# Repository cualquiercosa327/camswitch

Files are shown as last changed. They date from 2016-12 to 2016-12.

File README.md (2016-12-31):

# Little Camera Switcher

A special purpose keyboard with 15 keys, intended for hotkeying camera switches in Open Broadcast Studio. It's just a keyboard built with the Teensy 2.0, but it's made to be flexible and magnetic so it can attach to flat or curved metal surfaces.

This repository includes the Arduino sketches, CAD models in Rhino and STL format, and PCB layout in KiCad and Gerber. I fabricated the flex circuit on Pyralux using milling, but you can also use photochemical etching or toner transfer.

Everything here is dedicated to the public domain. ([CC0](https://wiki.creativecommons.org/wiki/CC0))

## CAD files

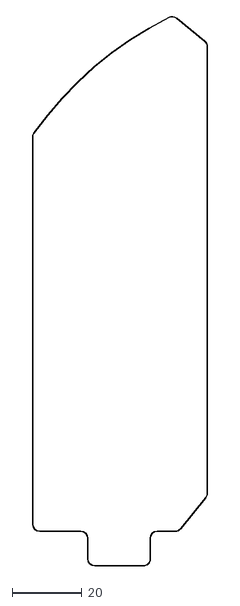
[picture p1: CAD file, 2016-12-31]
enclosure/pcb-outline.dxf
50.0 x 157.3

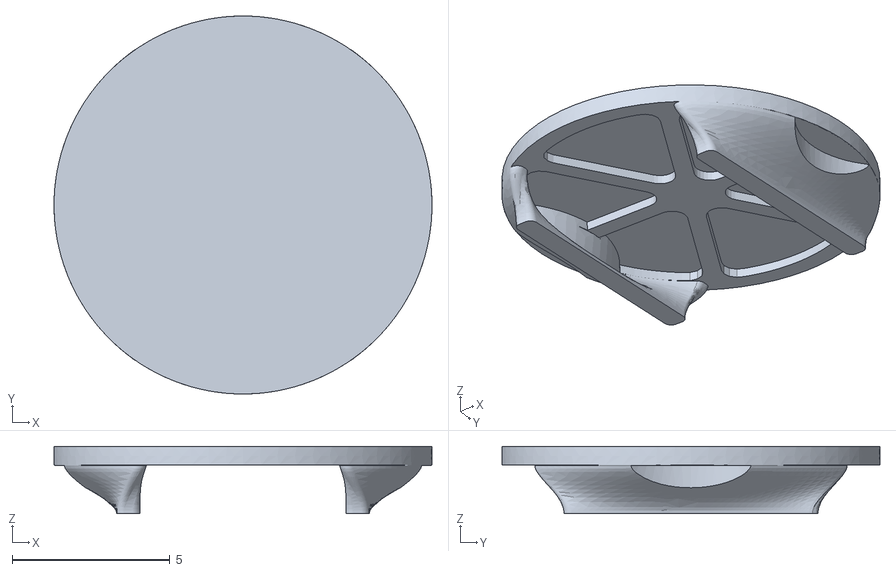
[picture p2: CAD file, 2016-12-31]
enclosure/prints/camswitch-key-insert-2.stl
12.0 x 12.0 x 2.14

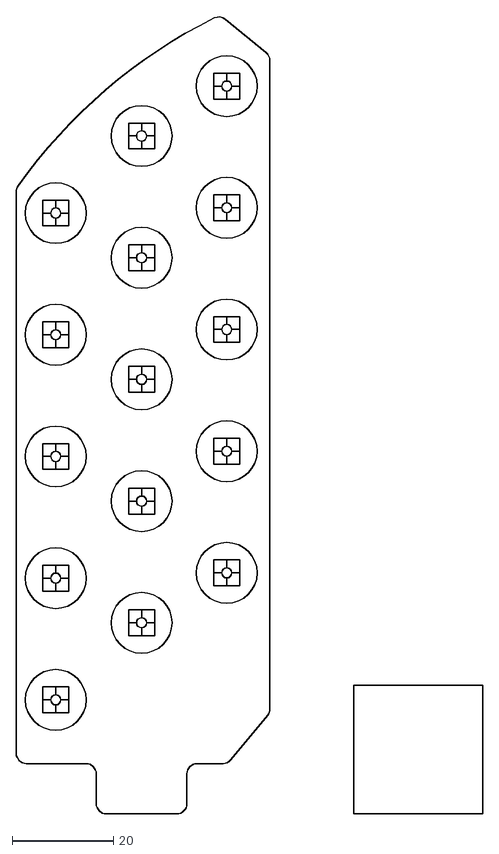
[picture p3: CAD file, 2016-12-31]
flexpcb/pcb-mechanical-constraints.dxf
92.0 x 157.3

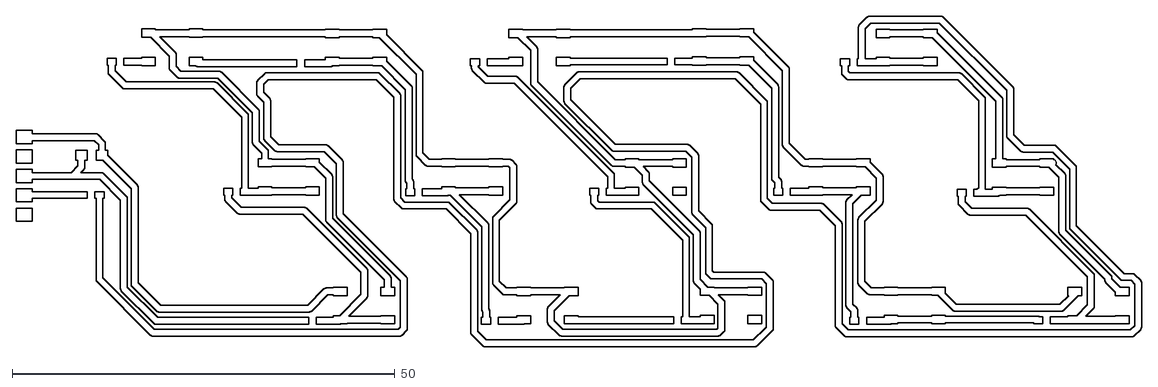
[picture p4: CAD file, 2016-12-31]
flexpcb/plots/camswitch-flexpcb-F.Cu.dxf
147.1 x 43.2

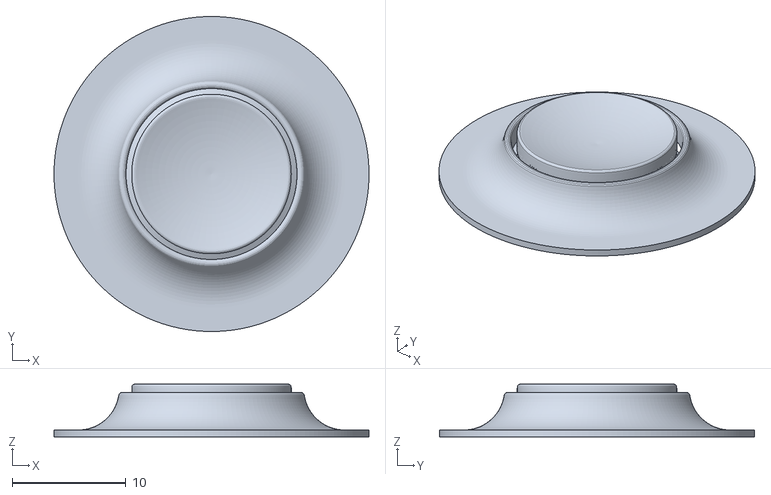
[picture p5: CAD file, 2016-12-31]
enclosure/prints/button-cover-test-8.stl
27.6 x 27.6 x 4.62

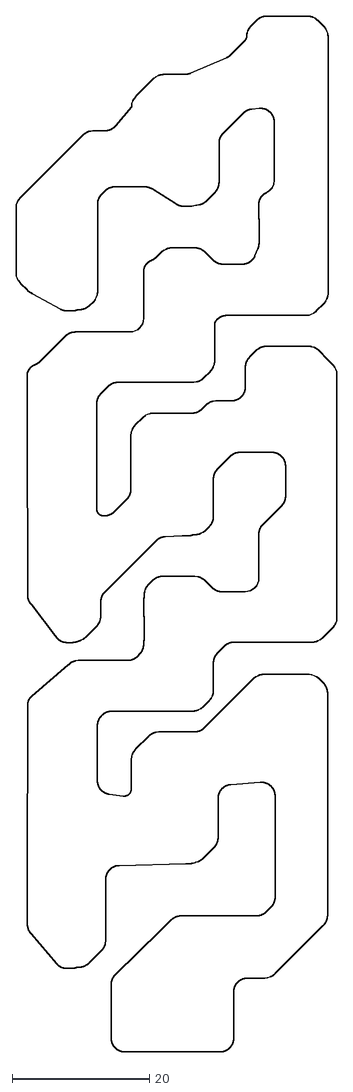
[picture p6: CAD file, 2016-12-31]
flexpcb/camswitch-curvy-outline.dxf
46.8 x 151.0

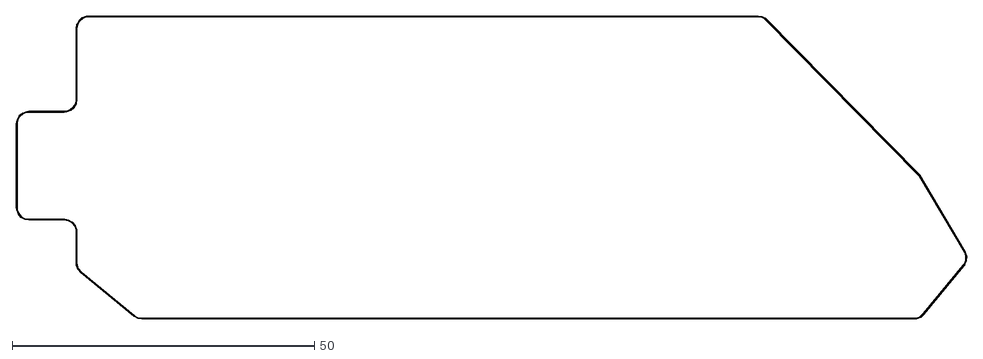
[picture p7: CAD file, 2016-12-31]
flexpcb/plots/camswitch-flexpcb-Edge.Cuts.dxf
157.2 x 50.1

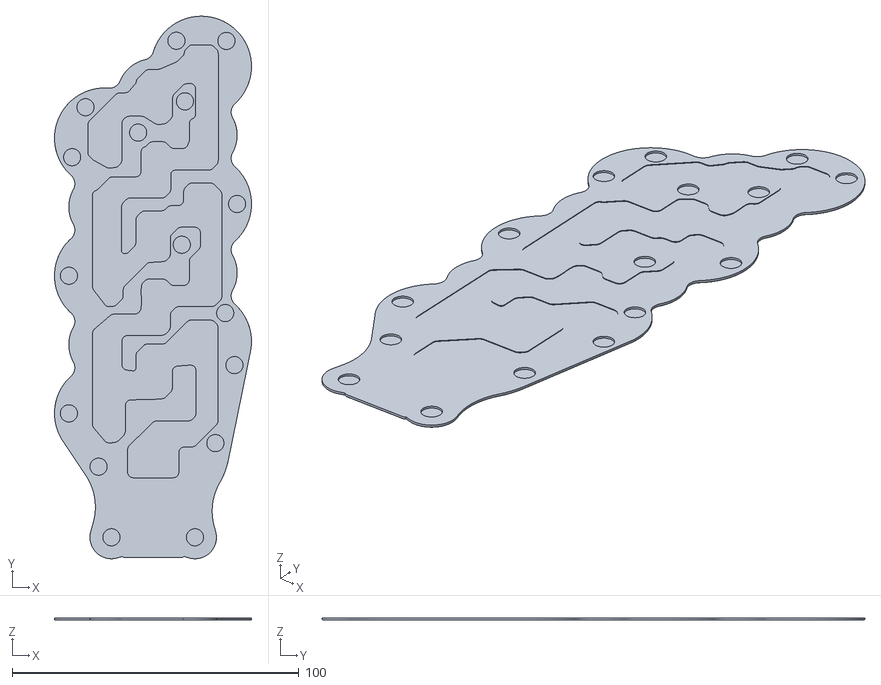
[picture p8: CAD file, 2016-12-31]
enclosure/prints/camswitch-bottom-1.stl
68.7 x 189.3 x 0.8

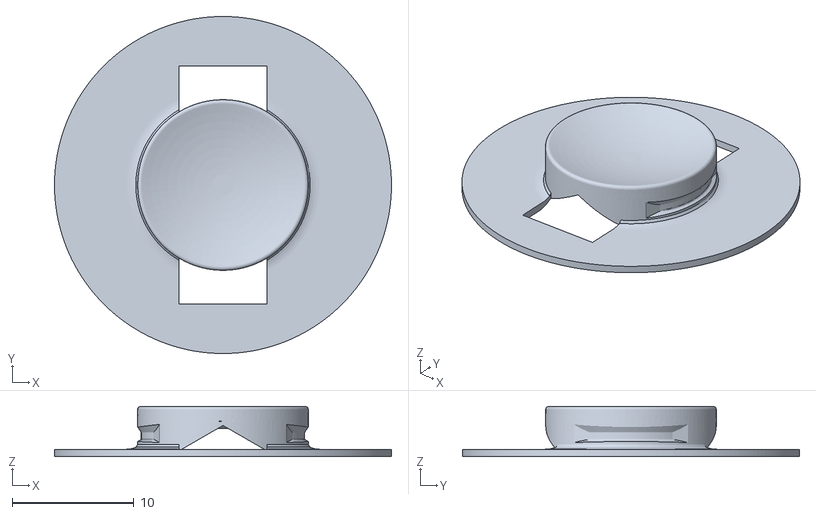
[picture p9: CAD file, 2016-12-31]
enclosure/prints/button-cover-test-6.stl
27.6 x 27.6 x 4.12

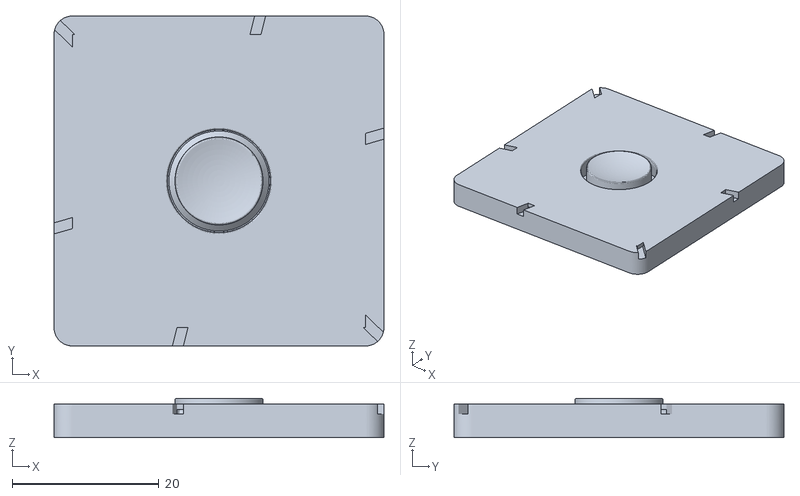
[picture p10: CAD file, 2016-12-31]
enclosure/prints/button-cover-test-1.stl
45.0 x 45.0 x 5.38

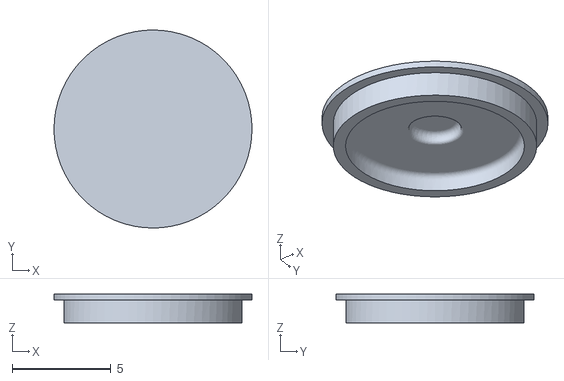
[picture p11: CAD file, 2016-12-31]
enclosure/prints/camswitch-key-insert.stl
10.00 x 10.0 x 1.45

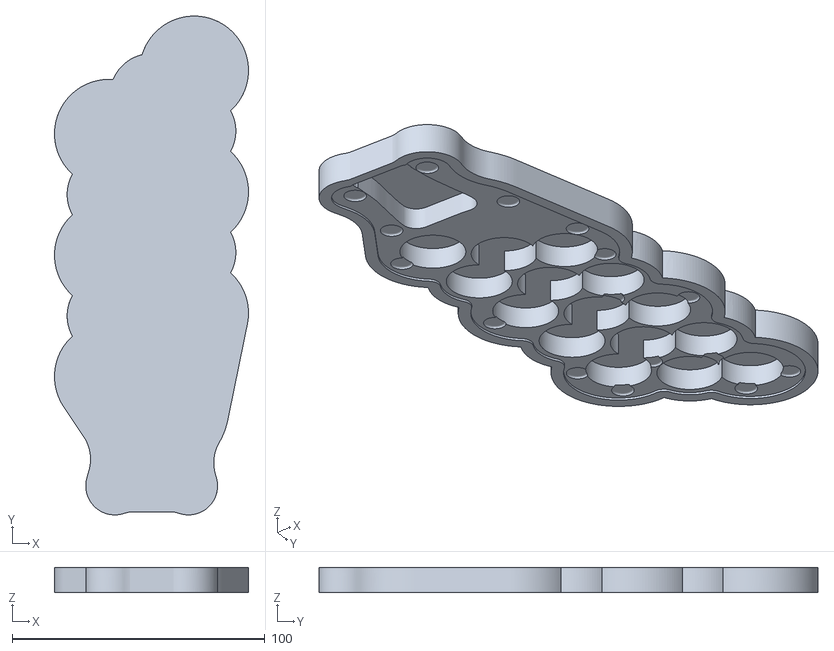
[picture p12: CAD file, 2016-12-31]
enclosure/prints/glueup-jig-1.stl
76.7 x 197.3 x 10.00

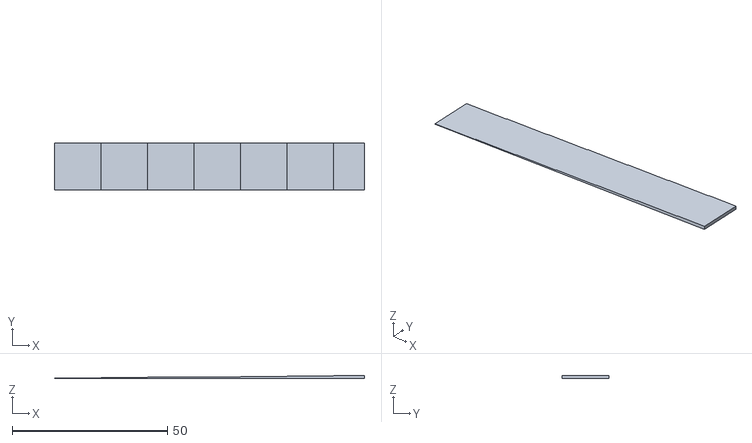
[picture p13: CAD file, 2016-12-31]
enclosure/prints/ninjaflex-thickness-test.stl
100.0 x 15.0 x 1.05

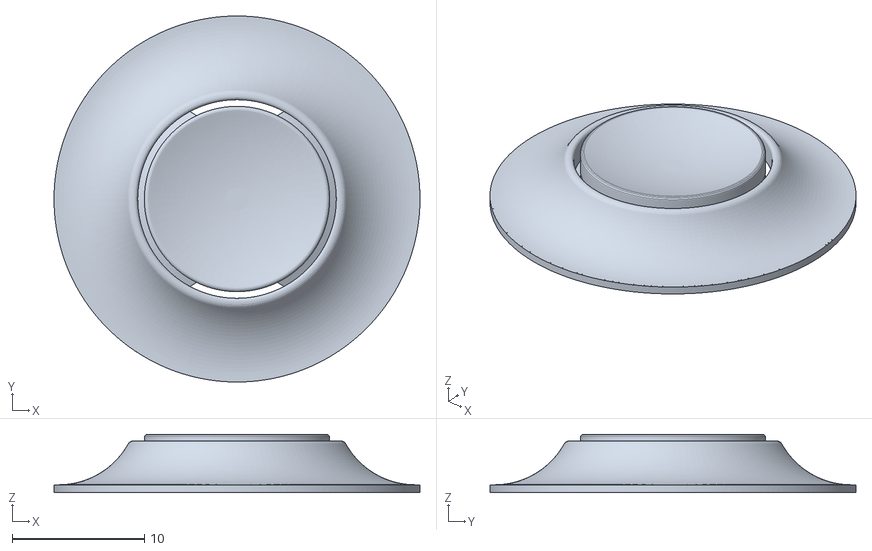
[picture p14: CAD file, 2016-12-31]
enclosure/prints/button-cover-test-7.stl
27.7 x 27.6 x 4.41

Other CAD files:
enclosure/button-module.3dm
enclosure/button-profile.3dm
enclosure/camswitcher.3dm

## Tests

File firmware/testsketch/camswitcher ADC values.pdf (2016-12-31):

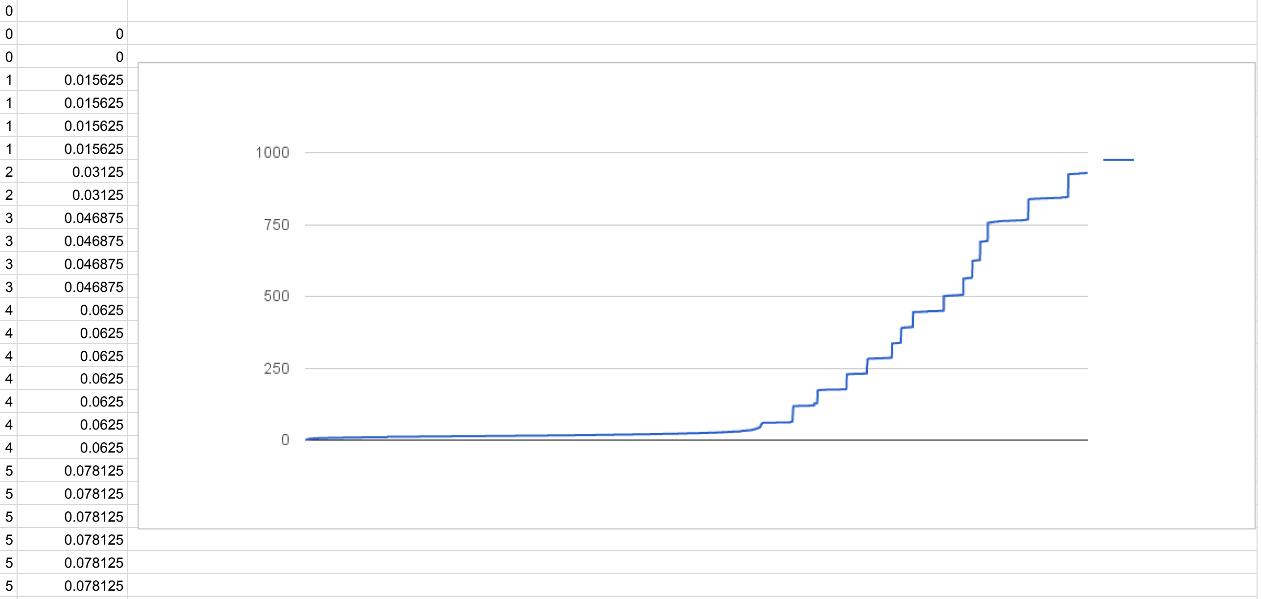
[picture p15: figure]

5 | 0.078125
5 | 0.078125
5 | 0.078125
5 | 0.078125
5 | 0.078125
6 | 0.09375
6 | 0.09375
6 | 0.09375
6 | 0.09375
6 | 0.09375
6 | 0.09375
6 | 0.09375
6 | 0.09375
6 | 0.09375
6 | 0.09375
6 | 0.09375
6 | 0.09375

6 | 0.09375
6 | 0.09375
6 | 0.09375
6 | 0.09375
6 | 0.09375
6 | 0.09375
6 | 0.09375
6 | 0.09375
6 | 0.09375
6 | 0.09375
7 | 0.109375
7 | 0.109375
7 | 0.109375
7 | 0.109375
7 | 0.109375
7 | 0.109375
7 | 0.109375
7 | 0.109375
7 | 0.109375
7 | 0.109375
7 | 0.109375
7 | 0.109375
7 | 0.109375
7 | 0.109375
7 | 0.109375
7 | 0.109375
7 | 0.109375
7 | 0.109375
7 | 0.109375
7 | 0.109375
7 | 0.109375
7 | 0.109375
7 | 0.109375
7 | 0.109375
7 | 0.109375
7 | 0.109375
7 | 0.109375
7 | 0.109375
7 | 0.109375
7 | 0.109375
7 | 0.109375
7 | 0.109375
7 | 0.109375

7 | 0.109375
7 | 0.109375
7 | 0.109375
7 | 0.109375
7 | 0.109375
7 | 0.109375
8 | 0.125
8 | 0.125
8 | 0.125
8 | 0.125
8 | 0.125
8 | 0.125
8 | 0.125
8 | 0.125
8 | 0.125
8 | 0.125
8 | 0.125
8 | 0.125
8 | 0.125
8 | 0.125
8 | 0.125
8 | 0.125
8 | 0.125
8 | 0.125
8 | 0.125
8 | 0.125
8 | 0.125
8 | 0.125
8 | 0.125
8 | 0.125
8 | 0.125
8 | 0.125
8 | 0.125
8 | 0.125
8 | 0.125
8 | 0.125
8 | 0.125
8 | 0.125
8 | 0.125
8 | 0.125
8 | 0.125
8 | 0.125

8 | 0.125
8 | 0.125
8 | 0.125
8 | 0.125
8 | 0.125
8 | 0.125
8 | 0.125
8 | 0.125
8 | 0.125
8 | 0.125
8 | 0.125
8 | 0.125
8 | 0.125
8 | 0.125
8 | 0.125
8 | 0.125
8 | 0.125
8 | 0.125
8 | 0.125
8 | 0.125
8 | 0.125
8 | 0.125
8 | 0.125
8 | 0.125
8 | 0.125
8 | 0.125
9 | 0.140625
9 | 0.140625
9 | 0.140625
9 | 0.140625
9 | 0.140625
9 | 0.140625
9 | 0.140625
9 | 0.140625
9 | 0.140625
9 | 0.140625
9 | 0.140625
9 | 0.140625
9 | 0.140625
9 | 0.140625
9 | 0.140625
9 | 0.140625

9 | 0.140625
9 | 0.140625
9 | 0.140625
9 | 0.140625
9 | 0.140625
9 | 0.140625
9 | 0.140625
9 | 0.140625
9 | 0.140625
9 | 0.140625
9 | 0.140625
9 | 0.140625
9 | 0.140625
9 | 0.140625
9 | 0.140625
9 | 0.140625
9 | 0.140625
9 | 0.140625
9 | 0.140625
9 | 0.140625
9 | 0.140625
9 | 0.140625
9 | 0.140625
9 | 0.140625
9 | 0.140625
9 | 0.140625
9 | 0.140625
9 | 0.140625
9 | 0.140625
9 | 0.140625
9 | 0.140625
9 | 0.140625
9 | 0.140625
9 | 0.140625
9 | 0.140625
9 | 0.140625
9 | 0.140625
9 | 0.140625
9 | 0.140625
9 | 0.140625
9 | 0.140625
9 | 0.140625

9 | 0.140625
9 | 0.140625
9 | 0.140625
9 | 0.140625
9 | 0.140625
9 | 0.140625
9 | 0.140625
9 | 0.140625
9 | 0.140625
9 | 0.140625
9 | 0.140625
9 | 0.140625
9 | 0.140625
9 | 0.140625
9 | 0.140625
9 | 0.140625
9 | 0.140625
9 | 0.140625
10 | 0.15625
10 | 0.15625
10 | 0.15625
10 | 0.15625
10 | 0.15625
10 | 0.15625
10 | 0.15625
10 | 0.15625
10 | 0.15625
10 | 0.15625
10 | 0.15625
10 | 0.15625
10 | 0.15625
10 | 0.15625
10 | 0.15625
10 | 0.15625
10 | 0.15625
10 | 0.15625
10 | 0.15625
10 | 0.15625
10 | 0.15625
10 | 0.15625
10 | 0.15625
10 | 0.15625

10 | 0.15625
10 | 0.15625
10 | 0.15625
10 | 0.15625
10 | 0.15625
10 | 0.15625
10 | 0.15625
10 | 0.15625
10 | 0.15625
10 | 0.15625
10 | 0.15625
10 | 0.15625
10 | 0.15625
10 | 0.15625
10 | 0.15625
10 | 0.15625
10 | 0.15625
10 | 0.15625
10 | 0.15625
10 | 0.15625
10 | 0.15625
10 | 0.15625
10 | 0.15625
10 | 0.15625
10 | 0.15625
10 | 0.15625
10 | 0.15625
10 | 0.15625
10 | 0.15625
10 | 0.15625
10 | 0.15625
10 | 0.15625
10 | 0.15625
10 | 0.15625
10 | 0.15625
10 | 0.15625
10 | 0.15625
10 | 0.15625
10 | 0.15625
10 | 0.15625
10 | 0.15625
10 | 0.15625

10 | 0.15625
10 | 0.15625
10 | 0.15625
10 | 0.15625
10 | 0.15625
10 | 0.15625
10 | 0.15625
10 | 0.15625
10 | 0.15625
10 | 0.15625
10 | 0.15625
10 | 0.15625
10 | 0.15625
10 | 0.15625
10 | 0.15625
10 | 0.15625
10 | 0.15625
10 | 0.15625
10 | 0.15625
10 | 0.15625
10 | 0.15625
10 | 0.15625
10 | 0.15625
10 | 0.15625
10 | 0.15625
10 | 0.15625
10 | 0.15625
10 | 0.15625
10 | 0.15625
10 | 0.15625
10 | 0.15625
10 | 0.15625
10 | 0.15625
10 | 0.15625
10 | 0.15625
10 | 0.15625
10 | 0.15625
10 | 0.15625
11 | 0.171875
11 | 0.171875
11 | 0.171875
11 | 0.171875

11 | 0.171875
11 | 0.171875
11 | 0.171875
11 | 0.171875
11 | 0.171875
11 | 0.171875
11 | 0.171875
11 | 0.171875
11 | 0.171875
11 | 0.171875
11 | 0.171875
11 | 0.171875
11 | 0.171875
11 | 0.171875
11 | 0.171875
11 | 0.171875
11 | 0.171875
11 | 0.171875
11 | 0.171875
11 | 0.171875
11 | 0.171875
11 | 0.171875
11 | 0.171875
11 | 0.171875
11 | 0.171875
11 | 0.171875
11 | 0.171875
11 | 0.171875
11 | 0.171875
11 | 0.171875
11 | 0.171875
11 | 0.171875
11 | 0.171875
11 | 0.171875
11 | 0.171875
11 | 0.171875
11 | 0.171875
11 | 0.171875
11 | 0.171875
11 | 0.171875
11 | 0.171875
11 | 0.171875

11 | 0.171875
11 | 0.171875
11 | 0.171875
11 | 0.171875
11 | 0.171875
11 | 0.171875
11 | 0.171875
11 | 0.171875
11 | 0.171875
11 | 0.171875
11 | 0.171875
11 | 0.171875
11 | 0.171875
11 | 0.171875
11 | 0.171875
11 | 0.171875
11 | 0.171875
11 | 0.171875
11 | 0.171875
11 | 0.171875
11 | 0.171875
11 | 0.171875
11 | 0.171875
11 | 0.171875
11 | 0.171875
11 | 0.171875
11 | 0.171875
11 | 0.171875
11 | 0.171875
11 | 0.171875
11 | 0.171875
11 | 0.171875
11 | 0.171875
11 | 0.171875
11 | 0.171875
11 | 0.171875
11 | 0.171875
11 | 0.171875
11 | 0.171875
11 | 0.171875
11 | 0.171875
11 | 0.171875

11 | 0.171875
11 | 0.171875
11 | 0.171875
11 | 0.171875
11 | 0.171875
11 | 0.171875
11 | 0.171875
11 | 0.171875
11 | 0.171875
11 | 0.171875
11 | 0.171875
11 | 0.171875
11 | 0.171875
11 | 0.171875
11 | 0.171875
11 | 0.171875
11 | 0.171875
11 | 0.171875
11 | 0.171875
11 | 0.171875
11 | 0.171875
11 | 0.171875
11 | 0.171875
11 | 0.171875
11 | 0.171875
11 | 0.171875
11 | 0.171875
11 | 0.171875
11 | 0.171875
11 | 0.171875
11 | 0.171875
11 | 0.171875
11 | 0.171875
11 | 0.171875
11 | 0.171875
11 | 0.171875
11 | 0.171875
11 | 0.171875
11 | 0.171875
11 | 0.171875
11 | 0.171875
12 | 0.1875

12 | 0.1875
12 | 0.1875
12 | 0.1875
12 | 0.1875
12 | 0.1875
12 | 0.1875
12 | 0.1875
12 | 0.1875
12 | 0.1875
12 | 0.1875
12 | 0.1875
12 | 0.1875
12 | 0.1875
12 | 0.1875
12 | 0.1875
12 | 0.1875
12 | 0.1875
12 | 0.1875
12 | 0.1875
12 | 0.1875
12 | 0.1875
12 | 0.1875
12 | 0.1875
12 | 0.1875
12 | 0.1875
12 | 0.1875
12 | 0.1875
12 | 0.1875
12 | 0.1875
12 | 0.1875
12 | 0.1875
12 | 0.1875
12 | 0.1875
12 | 0.1875
12 | 0.1875
12 | 0.1875
12 | 0.1875
12 | 0.1875
12 | 0.1875
12 | 0.1875
12 | 0.1875
12 | 0.1875

12 | 0.1875
12 | 0.1875
12 | 0.1875
12 | 0.1875
12 | 0.1875
12 | 0.1875
12 | 0.1875
12 | 0.1875
12 | 0.1875
12 | 0.1875
12 | 0.1875
12 | 0.1875
12 | 0.1875
12 | 0.1875
12 | 0.1875
12 | 0.1875
12 | 0.1875
12 | 0.1875
12 | 0.1875
12 | 0.1875
12 | 0.1875
12 | 0.1875
12 | 0.1875
12 | 0.1875
12 | 0.1875
12 | 0.1875
12 | 0.1875
12 | 0.1875
12 | 0.1875
12 | 0.1875
12 | 0.1875
12 | 0.1875
12 | 0.1875
12 | 0.1875
12 | 0.1875
12 | 0.1875
12 | 0.1875
12 | 0.1875
12 | 0.1875
12 | 0.1875
12 | 0.1875
12 | 0.1875

12 | 0.1875
12 | 0.1875
12 | 0.1875
12 | 0.1875
12 | 0.1875
12 | 0.1875
12 | 0.1875
12 | 0.1875
12 | 0.1875
12 | 0.1875
12 | 0.1875
12 | 0.1875
12 | 0.1875
12 | 0.1875
12 | 0.1875
12 | 0.1875
12 | 0.1875
12 | 0.1875
12 | 0.1875
12 | 0.1875
12 | 0.1875
12 | 0.1875
12 | 0.1875
12 | 0.1875
12 | 0.1875
12 | 0.1875
12 | 0.1875
12 | 0.1875
12 | 0.1875
12 | 0.1875
12 | 0.1875
12 | 0.1875
12 | 0.1875
12 | 0.1875
12 | 0.1875
12 | 0.1875
12 | 0.1875
12 | 0.1875
12 | 0.1875
12 | 0.1875
12 | 0.1875
12 | 0.1875

12 | 0.1875
12 | 0.1875
12 | 0.1875
12 | 0.1875
13 | 0.203125
13 | 0.203125
13 | 0.203125
13 | 0.203125
13 | 0.203125
13 | 0.203125
13 | 0.203125
13 | 0.203125
13 | 0.203125
13 | 0.203125
13 | 0.203125
13 | 0.203125
13 | 0.203125
13 | 0.203125
13 | 0.203125
13 | 0.203125
13 | 0.203125
13 | 0.203125
13 | 0.203125
13 | 0.203125
13 | 0.203125
13 | 0.203125
13 | 0.203125
13 | 0.203125
13 | 0.203125
13 | 0.203125
13 | 0.203125
13 | 0.203125
13 | 0.203125
13 | 0.203125
13 | 0.203125
13 | 0.203125
13 | 0.203125
13 | 0.203125
13 | 0.203125
13 | 0.203125
13 | 0.203125
13 | 0.203125

13 | 0.203125
13 | 0.203125
13 | 0.203125
13 | 0.203125
13 | 0.203125
13 | 0.203125
13 | 0.203125
13 | 0.203125
13 | 0.203125
13 | 0.203125
13 | 0.203125
13 | 0.203125
13 | 0.203125
13 | 0.203125
13 | 0.203125
13 | 0.203125
13 | 0.203125
13 | 0.203125
13 | 0.203125
13 | 0.203125
13 | 0.203125
13 | 0.203125
13 | 0.203125
13 | 0.203125
13 | 0.203125
13 | 0.203125
13 | 0.203125
13 | 0.203125
13 | 0.203125
13 | 0.203125
13 | 0.203125
13 | 0.203125
13 | 0.203125
13 | 0.203125
13 | 0.203125
13 | 0.203125
13 | 0.203125
13 | 0.203125
13 | 0.203125
13 | 0.203125
13 | 0.203125
13 | 0.203125

13 | 0.203125
13 | 0.203125
13 | 0.203125
13 | 0.203125
13 | 0.203125
13 | 0.203125
13 | 0.203125
13 | 0.203125
13 | 0.203125
13 | 0.203125
13 | 0.203125
13 | 0.203125
13 | 0.203125
13 | 0.203125
13 | 0.203125
13 | 0.203125
13 | 0.203125
13 | 0.203125
13 | 0.203125
13 | 0.203125
13 | 0.203125
13 | 0.203125
13 | 0.203125
13 | 0.203125
13 | 0.203125
13 | 0.203125
13 | 0.203125
13 | 0.203125
13 | 0.203125
13 | 0.203125
13 | 0.203125
13 | 0.203125
13 | 0.203125
13 | 0.203125
13 | 0.203125
13 | 0.203125
13 | 0.203125
13 | 0.203125
13 | 0.203125
13 | 0.203125
13 | 0.203125
13 | 0.203125

13 | 0.203125
13 | 0.203125
13 | 0.203125
13 | 0.203125
13 | 0.203125
13 | 0.203125
13 | 0.203125
13 | 0.203125
13 | 0.203125
13 | 0.203125
13 | 0.203125
13 | 0.203125
13 | 0.203125
14 | 0.21875
14 | 0.21875
14 | 0.21875
14 | 0.21875
14 | 0.21875
14 | 0.21875
14 | 0.21875
14 | 0.21875
14 | 0.21875
14 | 0.21875
14 | 0.21875
14 | 0.21875
14 | 0.21875
14 | 0.21875
14 | 0.21875
14 | 0.21875
14 | 0.21875
14 | 0.21875
14 | 0.21875
14 | 0.21875
14 | 0.21875
14 | 0.21875
14 | 0.21875
14 | 0.21875
14 | 0.21875
14 | 0.21875
14 | 0.21875
14 | 0.21875
14 | 0.21875

14 | 0.21875
14 | 0.21875
14 | 0.21875
14 | 0.21875
14 | 0.21875
14 | 0.21875
14 | 0.21875
14 | 0.21875
14 | 0.21875
14 | 0.21875
14 | 0.21875
14 | 0.21875
14 | 0.21875
14 | 0.21875
14 | 0.21875
14 | 0.21875
14 | 0.21875
14 | 0.21875
14 | 0.21875
14 | 0.21875
14 | 0.21875
14 | 0.21875
14 | 0.21875
14 | 0.21875
14 | 0.21875
14 | 0.21875
14 | 0.21875
14 | 0.21875
14 | 0.21875
14 | 0.21875
14 | 0.21875
14 | 0.21875
14 | 0.21875
14 | 0.21875
14 | 0.21875
14 | 0.21875
14 | 0.21875
14 | 0.21875
14 | 0.21875
14 | 0.21875
14 | 0.21875
14 | 0.21875

14 | 0.21875
14 | 0.21875
14 | 0.21875
14 | 0.21875
14 | 0.21875
14 | 0.21875
14 | 0.21875
14 | 0.21875
14 | 0.21875
14 | 0.21875
14 | 0.21875
14 | 0.21875
14 | 0.21875
14 | 0.21875
14 | 0.21875
14 | 0.21875
14 | 0.21875
14 | 0.21875
14 | 0.21875
14 | 0.21875
14 | 0.21875
14 | 0.21875
14 | 0.21875
14 | 0.21875
14 | 0.21875
14 | 0.21875
14 | 0.21875
14 | 0.21875
14 | 0.21875
14 | 0.21875
14 | 0.21875
14 | 0.21875
14 | 0.21875
14 | 0.21875
14 | 0.21875
14 | 0.21875
14 | 0.21875
14 | 0.21875
14 | 0.21875
14 | 0.21875
14 | 0.21875
14 | 0.21875

14 | 0.21875
14 | 0.21875
14 | 0.21875
14 | 0.21875
14 | 0.21875
14 | 0.21875
14 | 0.21875
14 | 0.21875
14 | 0.21875
14 | 0.21875
14 | 0.21875
15 | 0.234375
15 | 0.234375
15 | 0.234375
15 | 0.234375
15 | 0.234375
15 | 0.234375
15 | 0.234375
15 | 0.234375
15 | 0.234375
15 | 0.234375
15 | 0.234375
15 | 0.234375
15 | 0.234375
15 | 0.234375
15 | 0.234375
15 | 0.234375
15 | 0.234375
15 | 0.234375
15 | 0.234375
15 | 0.234375
15 | 0.234375
15 | 0.234375
15 | 0.234375
15 | 0.234375
15 | 0.234375
15 | 0.234375
15 | 0.234375
15 | 0.234375
15 | 0.234375
15 | 0.234375
15 | 0.234375

15 | 0.234375
15 | 0.234375
15 | 0.234375
15 | 0.234375
15 | 0.234375
15 | 0.234375
15 | 0.234375
15 | 0.234375
15 | 0.234375
15 | 0.234375
15 | 0.234375
15 | 0.234375
15 | 0.234375
15 | 0.234375
15 | 0.234375
15 | 0.234375
15 | 0.234375
15 | 0.234375
15 | 0.234375
15 | 0.234375
15 | 0.234375
15 | 0.234375
15 | 0.234375
15 | 0.234375
15 | 0.234375
15 | 0.234375
15 | 0.234375
15 | 0.234375
15 | 0.234375
15 | 0.234375
15 | 0.234375
15 | 0.234375
15 | 0.234375
15 | 0.234375
15 | 0.234375
15 | 0.234375
15 | 0.234375
15 | 0.234375
15 | 0.234375
15 | 0.234375
15 | 0.234375
15 | 0.234375

15 | 0.234375
15 | 0.234375
15 | 0.234375
15 | 0.234375
15 | 0.234375
15 | 0.234375
15 | 0.234375
15 | 0.234375
15 | 0.234375
15 | 0.234375
15 | 0.234375
15 | 0.234375
15 | 0.234375
15 | 0.234375
15 | 0.234375
15 | 0.234375
15 | 0.234375
15 | 0.234375
15 | 0.234375
15 | 0.234375
15 | 0.234375
15 | 0.234375
15 | 0.234375
15 | 0.234375
15 | 0.234375
15 | 0.234375
15 | 0.234375
15 | 0.234375
15 | 0.234375
15 | 0.234375
15 | 0.234375
15 | 0.234375
15 | 0.234375
15 | 0.234375
15 | 0.234375
15 | 0.234375
15 | 0.234375
15 | 0.234375
15 | 0.234375
15 | 0.234375
15 | 0.234375
15 | 0.234375

15 | 0.234375
15 | 0.234375
15 | 0.234375
15 | 0.234375
15 | 0.234375
15 | 0.234375
15 | 0.234375
15 | 0.234375
15 | 0.234375
15 | 0.234375
15 | 0.234375
15 | 0.234375
15 | 0.234375
15 | 0.234375
15 | 0.234375
16 | 0.25
16 | 0.25
16 | 0.25
16 | 0.25
16 | 0.25
16 | 0.25
16 | 0.25
16 | 0.25
16 | 0.25
16 | 0.25
16 | 0.25
16 | 0.25
16 | 0.25
16 | 0.25
16 | 0.25
16 | 0.25
16 | 0.25
16 | 0.25
16 | 0.25
16 | 0.25
16 | 0.25
16 | 0.25
16 | 0.25
16 | 0.25
16 | 0.25
16 | 0.25
16 | 0.25

16 | 0.25
16 | 0.25
16 | 0.25
16 | 0.25
16 | 0.25
16 | 0.25
16 | 0.25
16 | 0.25
16 | 0.25
16 | 0.25
16 | 0.25
16 | 0.25
16 | 0.25
16 | 0.25
16 | 0.25
16 | 0.25
16 | 0.25
16 | 0.25
16 | 0.25
16 | 0.25
16 | 0.25
16 | 0.25
16 | 0.25
16 | 0.25
16 | 0.25
16 | 0.25
16 | 0.25
16 | 0.25
16 | 0.25
16 | 0.25
16 | 0.25
16 | 0.25
16 | 0.25
16 | 0.25
16 | 0.25
16 | 0.25
16 | 0.25
16 | 0.25
16 | 0.25
16 | 0.25
16 | 0.25
16 | 0.25

16 | 0.25
16 | 0.25
16 | 0.25
16 | 0.25
16 | 0.25
16 | 0.25
16 | 0.25
16 | 0.25
16 | 0.25
16 | 0.25
16 | 0.25
16 | 0.25
16 | 0.25
16 | 0.25
16 | 0.25
16 | 0.25
16 | 0.25
16 | 0.25
16 | 0.25
16 | 0.25
16 | 0.25
16 | 0.25
16 | 0.25
16 | 0.25
16 | 0.25
16 | 0.25
16 | 0.25
16 | 0.25
16 | 0.25
16 | 0.25
16 | 0.25
16 | 0.25
16 | 0.25
16 | 0.25
16 | 0.25
16 | 0.25
16 | 0.25
16 | 0.25
16 | 0.25
16 | 0.25
16 | 0.25
16 | 0.25

17 | 0.265625
17 | 0.265625
17 | 0.265625
17 | 0.265625
17 | 0.265625
17 | 0.265625
17 | 0.265625
17 | 0.265625
17 | 0.265625
17 | 0.265625
17 | 0.265625
17 | 0.265625
17 | 0.265625
17 | 0.265625
17 | 0.265625
17 | 0.265625
17 | 0.265625
17 | 0.265625
17 | 0.265625
17 | 0.265625
17 | 0.265625
17 | 0.265625
17 | 0.265625
17 | 0.265625
17 | 0.265625
17 | 0.265625
17 | 0.265625
17 | 0.265625
17 | 0.265625
17 | 0.265625
17 | 0.265625
17 | 0.265625
17 | 0.265625
17 | 0.265625
17 | 0.265625
17 | 0.265625
17 | 0.265625
17 | 0.265625
17 | 0.265625
17 | 0.265625
17 | 0.265625
17 | 0.265625

17 | 0.265625
17 | 0.265625
17 | 0.265625
17 | 0.265625
17 | 0.265625
17 | 0.265625
17 | 0.265625
17 | 0.265625
17 | 0.265625
17 | 0.265625
17 | 0.265625
17 | 0.265625
17 | 0.265625
17 | 0.265625
17 | 0.265625
17 | 0.265625
17 | 0.265625
17 | 0.265625
17 | 0.265625
17 | 0.265625
17 | 0.265625
17 | 0.265625
17 | 0.265625
17 | 0.265625
17 | 0.265625
17 | 0.265625
17 | 0.265625
17 | 0.265625
17 | 0.265625
17 | 0.265625
17 | 0.265625
17 | 0.265625
17 | 0.265625
17 | 0.265625
17 | 0.265625
17 | 0.265625
17 | 0.265625
17 | 0.265625
17 | 0.265625
17 | 0.265625
17 | 0.265625
17 | 0.265625

18 | 0.28125
18 | 0.28125
18 | 0.28125
18 | 0.28125
18 | 0.28125
18 | 0.28125
18 | 0.28125
18 | 0.28125
18 | 0.28125
18 | 0.28125
18 | 0.28125
18 | 0.28125
18 | 0.28125
18 | 0.28125
18 | 0.28125
18 | 0.28125
18 | 0.28125
18 | 0.28125
18 | 0.28125
18 | 0.28125
18 | 0.28125
18 | 0.28125
18 | 0.28125
18 | 0.28125
18 | 0.28125
18 | 0.28125
18 | 0.28125
18 | 0.28125
18 | 0.28125
18 | 0.28125
18 | 0.28125
18 | 0.28125
18 | 0.28125
18 | 0.28125
18 | 0.28125
18 | 0.28125
18 | 0.28125
18 | 0.28125
18 | 0.28125
18 | 0.28125
18 | 0.28125
18 | 0.28125

18 | 0.28125
18 | 0.28125
18 | 0.28125
18 | 0.28125
18 | 0.28125
18 | 0.28125
18 | 0.28125
18 | 0.28125
18 | 0.28125
18 | 0.28125
18 | 0.28125
18 | 0.28125
18 | 0.28125
18 | 0.28125
18 | 0.28125
18 | 0.28125
18 | 0.28125
18 | 0.28125
18 | 0.28125
18 | 0.28125
18 | 0.28125
18 | 0.28125
18 | 0.28125
18 | 0.28125
18 | 0.28125
18 | 0.28125
18 | 0.28125
18 | 0.28125
18 | 0.28125
18 | 0.28125
18 | 0.28125
18 | 0.28125
19 | 0.296875
19 | 0.296875
19 | 0.296875
19 | 0.296875
19 | 0.296875
19 | 0.296875
19 | 0.296875
19 | 0.296875
19 | 0.296875
19 | 0.296875

19 | 0.296875
19 | 0.296875
19 | 0.296875
19 | 0.296875
19 | 0.296875
19 | 0.296875
19 | 0.296875
19 | 0.296875
19 | 0.296875
19 | 0.296875
19 | 0.296875
19 | 0.296875
19 | 0.296875
19 | 0.296875
19 | 0.296875
19 | 0.296875
19 | 0.296875
19 | 0.296875
19 | 0.296875
19 | 0.296875
19 | 0.296875
19 | 0.296875
19 | 0.296875
19 | 0.296875
19 | 0.296875
19 | 0.296875
19 | 0.296875
19 | 0.296875
19 | 0.296875
19 | 0.296875
19 | 0.296875
19 | 0.296875
19 | 0.296875
19 | 0.296875
19 | 0.296875
19 | 0.296875
19 | 0.296875
19 | 0.296875
19 | 0.296875
19 | 0.296875
19 | 0.296875
19 | 0.296875

19 | 0.296875
19 | 0.296875
19 | 0.296875
19 | 0.296875
19 | 0.296875
19 | 0.296875
19 | 0.296875
19 | 0.296875
19 | 0.296875
19 | 0.296875
19 | 0.296875
19 | 0.296875
19 | 0.296875
19 | 0.296875
19 | 0.296875
19 | 0.296875
19 | 0.296875
19 | 0.296875
19 | 0.296875
19 | 0.296875
19 | 0.296875
19 | 0.296875
19 | 0.296875
20 | 0.3125
20 | 0.3125
20 | 0.3125
20 | 0.3125
20 | 0.3125
20 | 0.3125
20 | 0.3125
20 | 0.3125
20 | 0.3125
20 | 0.3125
20 | 0.3125
20 | 0.3125
20 | 0.3125
20 | 0.3125
20 | 0.3125
20 | 0.3125
20 | 0.3125
20 | 0.3125
20 | 0.3125

20 | 0.3125
20 | 0.3125
20 | 0.3125
20 | 0.3125
20 | 0.3125
20 | 0.3125
20 | 0.3125
20 | 0.3125
20 | 0.3125
20 | 0.3125
20 | 0.3125
20 | 0.3125
20 | 0.3125
20 | 0.3125
20 | 0.3125
20 | 0.3125
20 | 0.3125
20 | 0.3125
20 | 0.3125
20 | 0.3125
20 | 0.3125
20 | 0.3125
20 | 0.3125
20 | 0.3125
20 | 0.3125
20 | 0.3125
20 | 0.3125
20 | 0.3125
20 | 0.3125
20 | 0.3125
20 | 0.3125
20 | 0.3125
20 | 0.3125
20 | 0.3125
20 | 0.3125
20 | 0.3125
20 | 0.3125
20 | 0.3125
20 | 0.3125
20 | 0.3125
20 | 0.3125
20 | 0.3125

20 | 0.3125
20 | 0.3125
20 | 0.3125
20 | 0.3125
20 | 0.3125
20 | 0.3125
20 | 0.3125
20 | 0.3125
20 | 0.3125
20 | 0.3125
21 | 0.328125
21 | 0.328125
21 | 0.328125
21 | 0.328125
21 | 0.328125
21 | 0.328125
21 | 0.328125
21 | 0.328125
21 | 0.328125
21 | 0.328125
21 | 0.328125
21 | 0.328125
21 | 0.328125
21 | 0.328125
21 | 0.328125
21 | 0.328125
21 | 0.328125
21 | 0.328125
21 | 0.328125
21 | 0.328125
21 | 0.328125
21 | 0.328125
21 | 0.328125
21 | 0.328125
21 | 0.328125
21 | 0.328125
21 | 0.328125
21 | 0.328125
21 | 0.328125
21 | 0.328125
21 | 0.328125
21 | 0.328125

21 | 0.328125
21 | 0.328125
21 | 0.328125
21 | 0.328125
21 | 0.328125
21 | 0.328125
21 | 0.328125
21 | 0.328125
21 | 0.328125
21 | 0.328125
21 | 0.328125
21 | 0.328125
21 | 0.328125
21 | 0.328125
21 | 0.328125
21 | 0.328125
21 | 0.328125
21 | 0.328125
21 | 0.328125
21 | 0.328125
22 | 0.34375
22 | 0.34375
22 | 0.34375
22 | 0.34375
22 | 0.34375
22 | 0.34375
22 | 0.34375
22 | 0.34375
22 | 0.34375
22 | 0.34375
22 | 0.34375
22 | 0.34375
22 | 0.34375
22 | 0.34375
22 | 0.34375
22 | 0.34375
22 | 0.34375
22 | 0.34375
22 | 0.34375
22 | 0.34375
22 | 0.34375
22 | 0.34375

22 | 0.34375
22 | 0.34375
22 | 0.34375
22 | 0.34375
22 | 0.34375
22 | 0.34375
22 | 0.34375
22 | 0.34375
22 | 0.34375
22 | 0.34375
22 | 0.34375
22 | 0.34375
22 | 0.34375
22 | 0.34375
22 | 0.34375
22 | 0.34375
22 | 0.34375
22 | 0.34375
22 | 0.34375
22 | 0.34375
22 | 0.34375
22 | 0.34375
22 | 0.34375
22 | 0.34375
22 | 0.34375
22 | 0.34375
22 | 0.34375
22 | 0.34375
22 | 0.34375
22 | 0.34375
22 | 0.34375
22 | 0.34375
22 | 0.34375
22 | 0.34375
22 | 0.34375
22 | 0.34375
22 | 0.34375
22 | 0.34375
22 | 0.34375
22 | 0.34375
23 | 0.359375
23 | 0.359375

23 | 0.359375
23 | 0.359375
23 | 0.359375
23 | 0.359375
23 | 0.359375
23 | 0.359375
23 | 0.359375
23 | 0.359375
23 | 0.359375
23 | 0.359375
23 | 0.359375
23 | 0.359375
23 | 0.359375
23 | 0.359375
23 | 0.359375
23 | 0.359375
23 | 0.359375
23 | 0.359375
23 | 0.359375
23 | 0.359375
23 | 0.359375
23 | 0.359375
23 | 0.359375
23 | 0.359375
23 | 0.359375
23 | 0.359375
23 | 0.359375
23 | 0.359375
23 | 0.359375
23 | 0.359375
23 | 0.359375
23 | 0.359375
23 | 0.359375
23 | 0.359375
23 | 0.359375
23 | 0.359375
23 | 0.359375
24 | 0.375
24 | 0.375
24 | 0.375
24 | 0.375
24 | 0.375

24 | 0.375
24 | 0.375
24 | 0.375
24 | 0.375
24 | 0.375
24 | 0.375
24 | 0.375
24 | 0.375
24 | 0.375
24 | 0.375
24 | 0.375
24 | 0.375
24 | 0.375
24 | 0.375
24 | 0.375
24 | 0.375
24 | 0.375
24 | 0.375
24 | 0.375
24 | 0.375
24 | 0.375
24 | 0.375
24 | 0.375
24 | 0.375
24 | 0.375
24 | 0.375
24 | 0.375
24 | 0.375
24 | 0.375
24 | 0.375
24 | 0.375
24 | 0.375
24 | 0.375
24 | 0.375
24 | 0.375
24 | 0.375
24 | 0.375
24 | 0.375
24 | 0.375
24 | 0.375
24 | 0.375
24 | 0.375

24 | 0.375
25 | 0.390625
25 | 0.390625
25 | 0.390625
25 | 0.390625
25 | 0.390625
25 | 0.390625
25 | 0.390625
25 | 0.390625
25 | 0.390625
25 | 0.390625
25 | 0.390625
25 | 0.390625
25 | 0.390625
25 | 0.390625
25 | 0.390625
25 | 0.390625
25 | 0.390625
25 | 0.390625
25 | 0.390625
25 | 0.390625
25 | 0.390625
25 | 0.390625
25 | 0.390625
25 | 0.390625
25 | 0.390625
25 | 0.390625
25 | 0.390625
25 | 0.390625
25 | 0.390625
25 | 0.390625
25 | 0.390625
25 | 0.390625
25 | 0.390625
25 | 0.390625
25 | 0.390625
25 | 0.390625
26 | 0.40625
26 | 0.40625
26 | 0.40625
26 | 0.40625
26 | 0.40625

26 | 0.40625
26 | 0.40625
26 | 0.40625
26 | 0.40625
26 | 0.40625
26 | 0.40625
26 | 0.40625
26 | 0.40625
26 | 0.40625
26 | 0.40625
26 | 0.40625
26 | 0.40625
26 | 0.40625
26 | 0.40625
26 | 0.40625
26 | 0.40625
26 | 0.40625
26 | 0.40625
26 | 0.40625
26 | 0.40625
26 | 0.40625
26 | 0.40625
26 | 0.40625
26 | 0.40625
26 | 0.40625
26 | 0.40625
26 | 0.40625
26 | 0.40625
26 | 0.40625
26 | 0.40625
27 | 0.421875
27 | 0.421875
27 | 0.421875
27 | 0.421875
27 | 0.421875
27 | 0.421875
27 | 0.421875
27 | 0.421875
27 | 0.421875
27 | 0.421875
27 | 0.421875
27 | 0.421875

27 | 0.421875
27 | 0.421875
27 | 0.421875
27 | 0.421875
27 | 0.421875
27 | 0.421875
27 | 0.421875
27 | 0.421875
27 | 0.421875
27 | 0.421875
27 | 0.421875
27 | 0.421875
28 | 0.4375
28 | 0.4375
28 | 0.4375
28 | 0.4375
28 | 0.4375
28 | 0.4375
28 | 0.4375
28 | 0.4375
28 | 0.4375
28 | 0.4375
28 | 0.4375
28 | 0.4375
28 | 0.4375
28 | 0.4375
28 | 0.4375
28 | 0.4375
28 | 0.4375
28 | 0.4375
28 | 0.4375
28 | 0.4375
28 | 0.4375
29 | 0.453125
29 | 0.453125
29 | 0.453125
29 | 0.453125
29 | 0.453125
29 | 0.453125
29 | 0.453125
29 | 0.453125
29 | 0.453125

29 | 0.453125
29 | 0.453125
29 | 0.453125
29 | 0.453125
29 | 0.453125
29 | 0.453125
29 | 0.453125
29 | 0.453125
29 | 0.453125
29 | 0.453125
30 | 0.46875
30 | 0.46875
30 | 0.46875
30 | 0.46875
30 | 0.46875
30 | 0.46875
30 | 0.46875
30 | 0.46875
30 | 0.46875
30 | 0.46875
30 | 0.46875
30 | 0.46875
30 | 0.46875
30 | 0.46875
30 | 0.46875
30 | 0.46875
30 | 0.46875
30 | 0.46875
30 | 0.46875
30 | 0.46875
30 | 0.46875
30 | 0.46875
30 | 0.46875
30 | 0.46875
30 | 0.46875
30 | 0.46875
31 | 0.484375
31 | 0.484375
31 | 0.484375
31 | 0.484375
31 | 0.484375
31 | 0.484375

31 | 0.484375
31 | 0.484375
31 | 0.484375
31 | 0.484375
31 | 0.484375
32 | 0.5
32 | 0.5
32 | 0.5
32 | 0.5
32 | 0.5
32 | 0.5
32 | 0.5
32 | 0.5
32 | 0.5
32 | 0.5
32 | 0.5
32 | 0.5
32 | 0.5
32 | 0.5
32 | 0.5
32 | 0.5
33 | 0.515625
33 | 0.515625
33 | 0.515625
33 | 0.515625
33 | 0.515625
33 | 0.515625
33 | 0.515625
33 | 0.515625
33 | 0.515625
33 | 0.515625
33 | 0.515625
34 | 0.53125
34 | 0.53125
34 | 0.53125
34 | 0.53125
34 | 0.53125
34 | 0.53125
34 | 0.53125
34 | 0.53125
34 | 0.53125
34 | 0.53125

35 | 0.546875
35 | 0.546875
35 | 0.546875
35 | 0.546875
35 | 0.546875
36 | 0.5625
36 | 0.5625
36 | 0.5625
36 | 0.5625
36 | 0.5625
36 | 0.5625
37 | 0.578125
37 | 0.578125
38 | 0.59375
38 | 0.59375
38 | 0.59375
38 | 0.59375
38 | 0.59375
39 | 0.609375
39 | 0.609375
39 | 0.609375
40 | 0.625
40 | 0.625
40 | 0.625
40 | 0.625
40 | 0.625
40 | 0.625
41 | 0.640625
41 | 0.640625
41 | 0.640625
42 | 0.65625
43 | 0.671875
44 | 0.6875
44 | 0.6875
44 | 0.6875
44 | 0.6875
45 | 0.703125
46 | 0.71875
47 | 0.734375
49 | 0.765625
53 | 0.828125
53 | 0.828125
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

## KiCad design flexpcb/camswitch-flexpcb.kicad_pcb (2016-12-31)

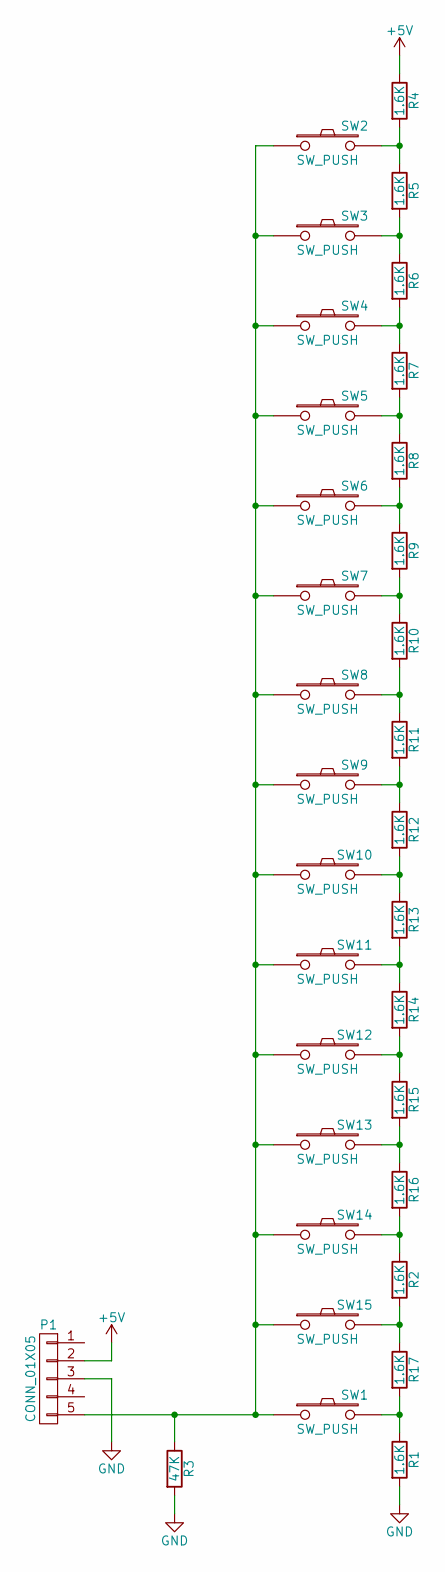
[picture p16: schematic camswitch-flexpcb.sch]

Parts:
P1: CONN_01X05; Pin_Header_Straight_1x05
R1, R2, R4, R5, R6, R7, R8, R9, R10, R11, R12, R13, R14, R15, R16, R17: 1.6K; R_0603_HandSoldering
R3: 47K; R_0805_HandSoldering
SW1, SW2, SW3, SW4, SW5, SW6, SW7, SW8, SW9, SW10, SW11, SW12, SW13, SW14, SW15: SW_PUSH; SW_SPST_SKQG

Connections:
+5V: P1.2, R4.1
GND: P1.3, R1.2, R3.2
unnamed: P1.5, R3.1, SW1.1, SW2.1, SW3.1, SW4.1, SW5.1, SW6.1, SW7.1, SW8.1, SW9.1, SW10.1, SW11.1, SW12.1, SW13.1, SW14.1, SW15.1
unnamed: R1.1, R17.2, SW1.2
unnamed: R4.2, R5.1, SW2.2
unnamed: R5.2, R6.1, SW3.2
unnamed: R6.2, R7.1, SW4.2
unnamed: R7.2, R8.1, SW5.2
unnamed: R8.2, R9.1, SW6.2
unnamed: R9.2, R10.1, SW7.2
unnamed: R10.2, R11.1, SW8.2
unnamed: R11.2, R12.1, SW9.2
unnamed: R12.2, R13.1, SW10.2
unnamed: R13.2, R14.1, SW11.2
unnamed: R14.2, R15.1, SW12.2
unnamed: R15.2, R16.1, SW13.2
unnamed: R2.1, R16.2, SW14.2
unnamed: R2.2, R17.1, SW15.2

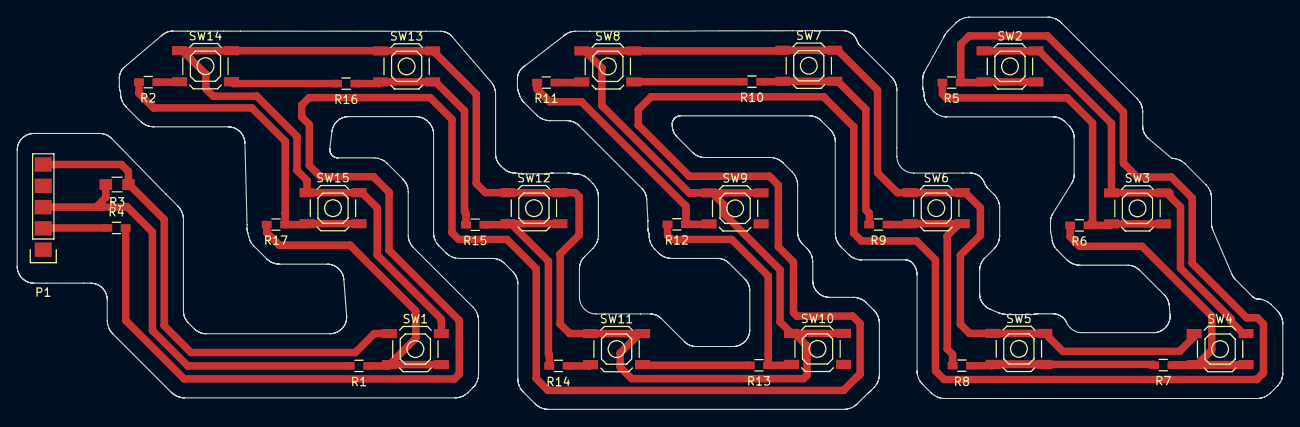
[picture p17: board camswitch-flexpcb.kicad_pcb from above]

Board: 2 copper layers, 151.0 x 46.8 mm, 33 parts (0 on the bottom side), 18 nets.

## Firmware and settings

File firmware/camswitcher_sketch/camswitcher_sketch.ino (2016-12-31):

const int analog_pin = 11;

const int modifiers = MODIFIERKEY_SHIFT | MODIFIERKEY_ALT;

static const struct {
  int adc;
  int key;
} key_table[] = {
  { 70,  KEY_O },
  { 119, KEY_N },
  { 176, KEY_M },
  { 231, KEY_J },
  { 284, KEY_K },
  { 338, KEY_L },
  { 391, KEY_I },
  { 446, KEY_H },
  { 502, KEY_G },
  { 564, KEY_D },
  { 624, KEY_E },
  { 691, KEY_F },
  { 762, KEY_C },
  { 839, KEY_B },
  { 927, KEY_A },
  { 0, 0 }
};

void setup()
{}

void loop()
{
  // Look for a stable voltage plateau

  int saved_reading = 0;
  int consecutive = 0;
  while (consecutive < 3) {
    delay(1);
    int reading = analogRead(analog_pin);
    if (reading == saved_reading) {
      consecutive++;
    } else {
      consecutive = 1;
      saved_reading = reading;
    }
  }
  
  // Find closest key in the lookup table

  int i = 0;
  int key = key_table[i].key;
  int closest = abs(key_table[i].adc - saved_reading);
  do {
    i++;
    int dist = abs(key_table[i].adc - saved_reading);
    if (dist < closest) {
      key = key_table[i].key;
      closest = dist;
    }
  } while (key_table[i].key);
  if (key == 0) {
    // Idle
    return;
  }

  // Press key

  Keyboard.set_modifier(modifiers);
  Keyboard.set_key1(key);
  Keyboard.send_now();

  // Wait for release, including the long capacitor discharge tail

  while (analogRead(analog_pin) > 15) {
    delay(1);
  }
  
  Keyboard.releaseAll();
  Keyboard.send_now();
}

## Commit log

2016-12-31 Initial import
    [button-cover-test-1.stl, button-cover-test-6.stl, button-cover-test-7.stl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]
2016-12-31 CAD versioning cleanup
    [camswitcher 001.3dm, camswitcher 002.3dm, ninjaflex-thickness-test.stl]
